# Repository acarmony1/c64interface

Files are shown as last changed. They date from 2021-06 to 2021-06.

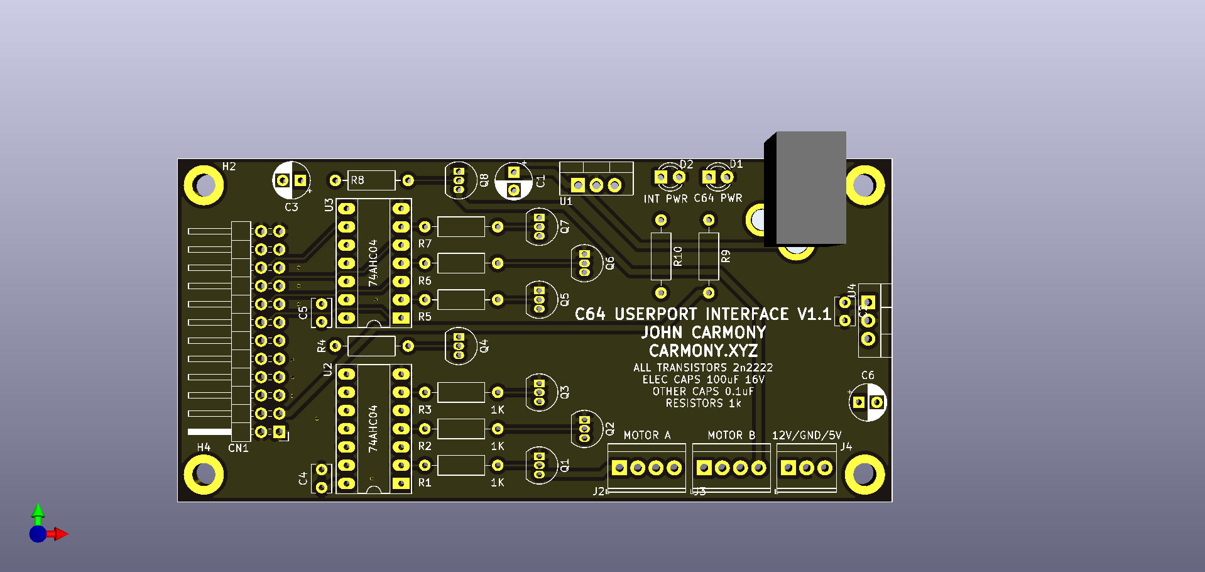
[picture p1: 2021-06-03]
kicad/c64interface.png

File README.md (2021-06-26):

# c64interface
 Commdore 64 Userport Interface
 
 I have been working on interface for the Commodore 64's userport. This interface allows user to use the C64 like you would any microcontroller. At this time it only turns on and off 8 pins, pins PB0-7.

There are many things that can be done with the C64's userport, which I will be looking into adding in the future. For now take a look at acarmony1/c64interface: Commodore 64 Userport Interface (github.com) for more information, schematics, and a demo program.

https://carmony.xyz/10-commodore/commodore-64-projects/9-c64-userport-interface.html

https://carmony.xyz/

Use the interface.prg as a demo to use this interface. Take note if the interface is powered up, and the C64 is off all ports are turned ON. This was the design I used from the Projects for the C64 book. In future versions, I may impletment a 'fail safe', where if no power from the C64 the unit shuts down.

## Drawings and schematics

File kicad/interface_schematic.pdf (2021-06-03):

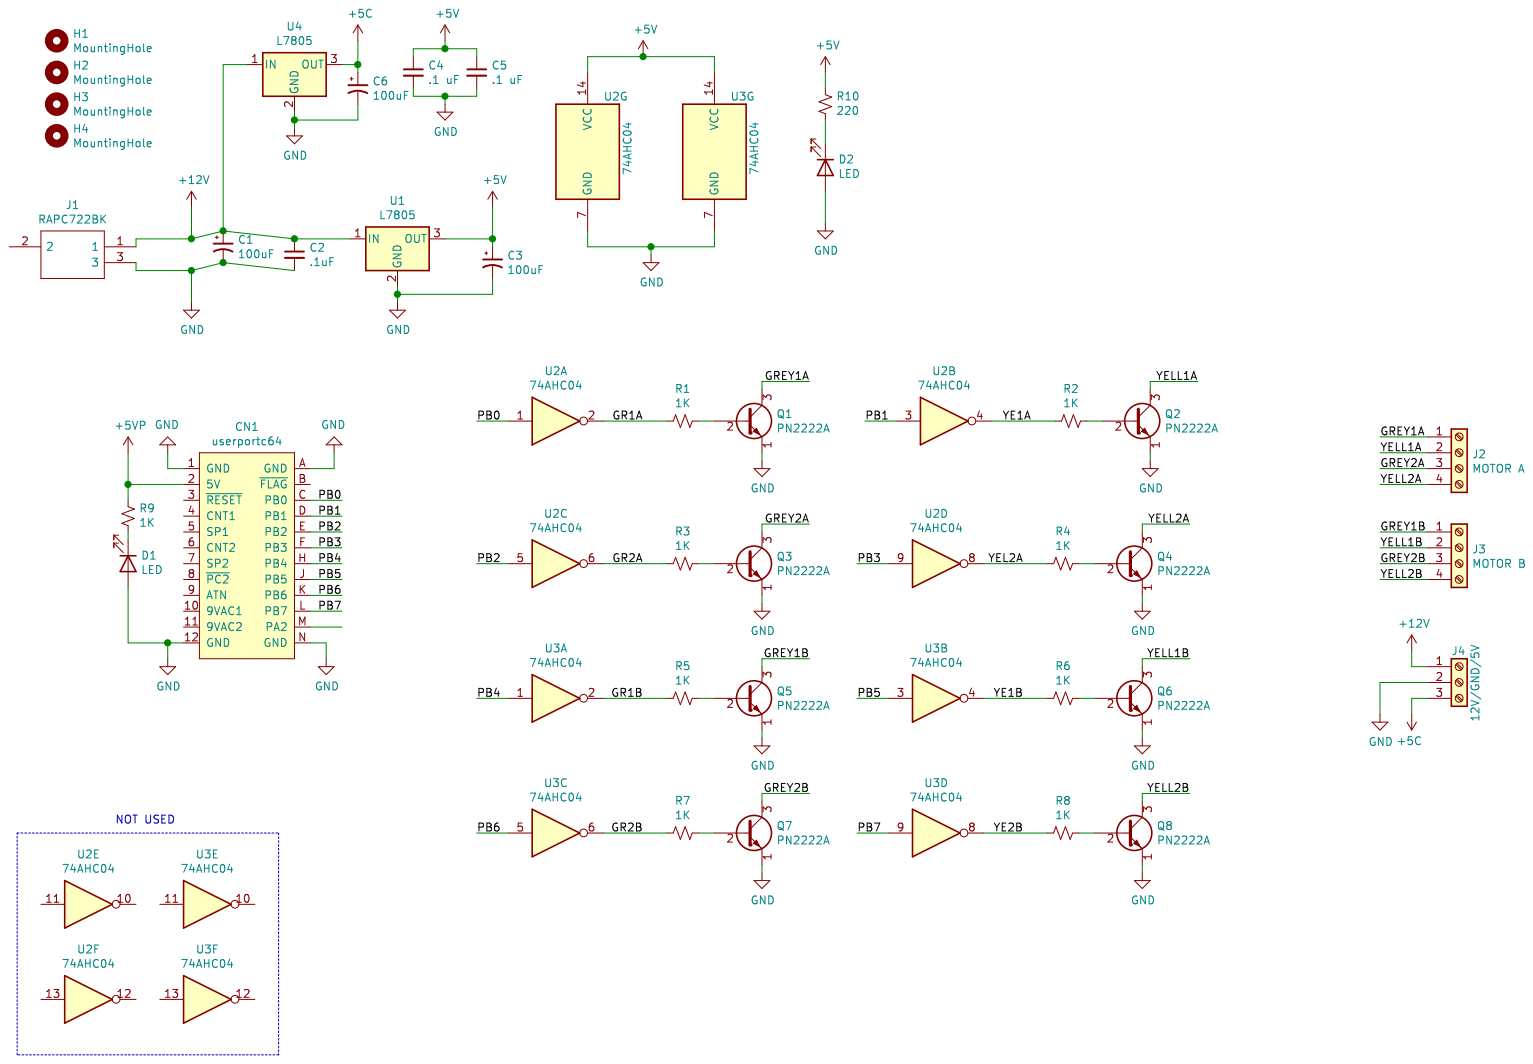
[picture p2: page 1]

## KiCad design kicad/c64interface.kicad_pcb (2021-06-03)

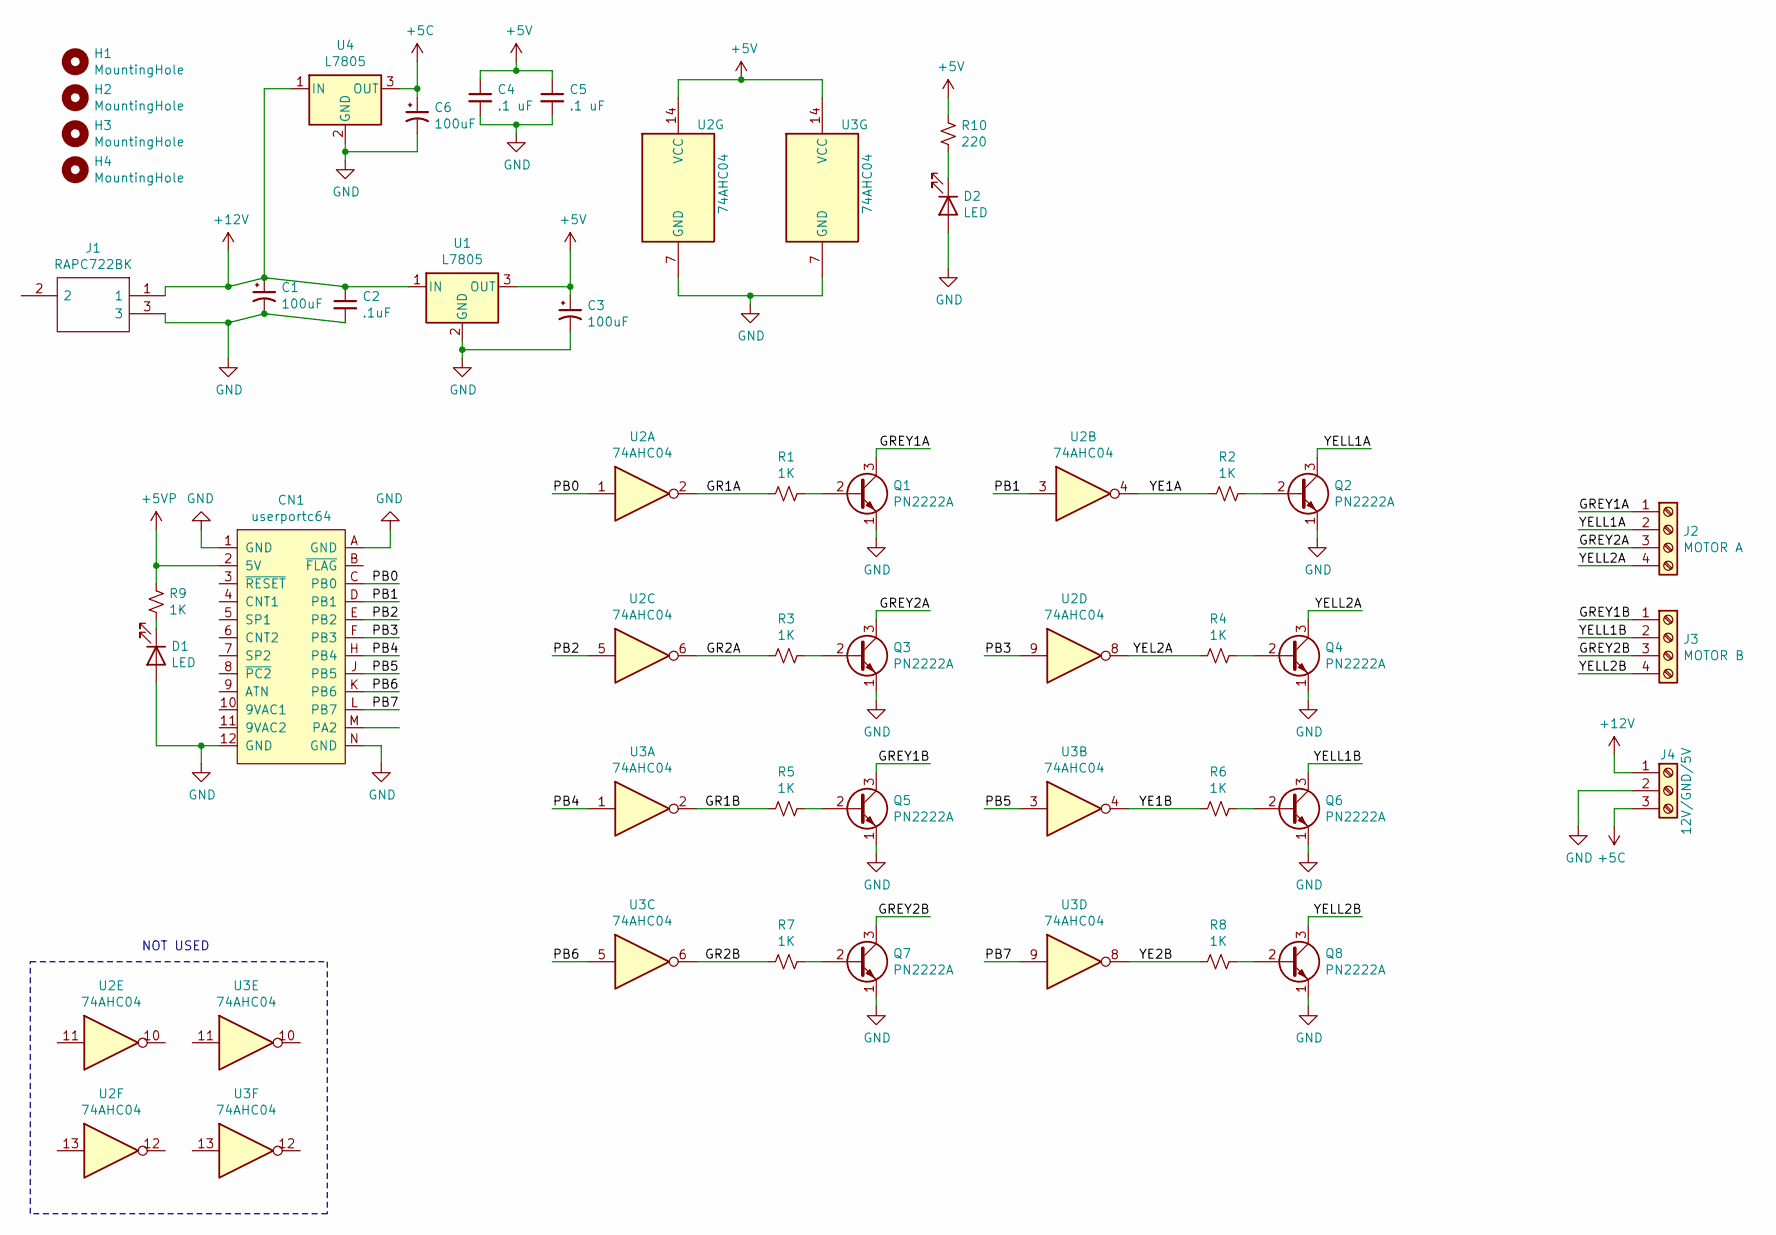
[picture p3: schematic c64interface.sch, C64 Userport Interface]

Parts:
C1, C3, C6: 100uF; CP_Radial_D5.0mm_P2.50mm
C2: .1uF; C_Disc_D3.8mm_W2.6mm_P2.50mm
C4, C5: .1 uF; C_Disc_D3.8mm_W2.6mm_P2.50mm
CN1: userportc64; PinHeader_2x12_P2.54mm_Horizontal
D1, D2: LED; LED_D3.0mm
H1, H2, H3, H4: MountingHole; MountingHole_3.2mm_M3_DIN965_Pad
J1: RAPC722BK; Mouser Part Number 502-RAPC722BK
J2: MOTOR A; TerminalBlock_TE_282834-4_1x04_P2.54mm_Horizontal
J3: MOTOR B; TerminalBlock_TE_282834-4_1x04_P2.54mm_Horizontal
J4: 12V/GND/5V; TerminalBlock_TE_282834-3_1x03_P2.54mm_Horizontal
Q1, Q2, Q3, Q4, Q5, Q6, Q7, Q8: PN2222A; TO-92_Inline
R1, R2, R3, R4, R5, R6, R7, R8, R9: 1K; R_Axial_DIN0207_L6.3mm_D2.5mm_P10.16mm_Horizontal
R10: 220; R_Axial_DIN0207_L6.3mm_D2.5mm_P10.16mm_Horizontal
U1, U4: L7805; TO-220-3_Vertical
U2, U3: 74AHC04; DIP-14_W7.62mm_Socket_LongPads

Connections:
+5C: C6.1, J4.3, U4.3 (OUT)
+5V: C3.1, C4.1, C5.1, R10.2, U1.3 (OUT), U2.14 (VCC), U3.14 (VCC)
+5VP: CN1.2 (5V), R9.2
+12V: C1.1, C2.1, J1.1, J4.1, U1.1 (IN), U4.1 (IN)
/GR1A: R1.2, U2.2
/GR1B: R5.2, U3.2
/GR2A: R3.2, U2.6
/GR2B: R7.2, U3.6
/GREY1A: J2.1, Q1.3 (C)
/GREY1B: J3.1, Q5.3 (C)
/GREY2A: J2.3, Q3.3 (C)
/GREY2B: J3.3, Q7.3 (C)
/PB0: CN1.C (PB0), U2.1
/PB1: CN1.D (PB1), U2.3
/PB2: CN1.E (PB2), U2.5
/PB3: CN1.F (PB3), U2.9
/PB4: CN1.H (PB4), U3.1
/PB5: CN1.J (PB5), U3.3
/PB6: CN1.K (PB6), U3.5
/PB7: CN1.L (PB7), U3.9
/YE1A: R2.2, U2.4
/YE1B: R6.2, U3.4
/YE2B: R8.2, U3.8
/YEL2A: R4.2, U2.8
/YELL1A: J2.2, Q2.3 (C)
/YELL1B: J3.2, Q6.3 (C)
/YELL2A: J2.4, Q4.3 (C)
/YELL2B: J3.4, Q8.3 (C)
GND: C1.2, C2.2, C3.2, C4.2, C5.2, C6.2, CN1.1 (GND), CN1.12 (GND), CN1.A (GND), CN1.N (GND), D1.2 (A), D2.2 (A), J1.3, J4.2, Q1.1 (E), Q2.1 (E), Q3.1 (E), Q4.1 (E), Q5.1 (E), Q6.1 (E), Q7.1 (E), Q8.1 (E), U1.2 (GND), U2.7 (GND), U3.7 (GND), U4.2 (GND)
unnamed: D1.1 (K), R9.1
unnamed: D2.1 (K), R10.1
unnamed: Q1.2 (B), R1.1
unnamed: Q2.2 (B), R2.1
unnamed: Q3.2 (B), R3.1
unnamed: Q4.2 (B), R4.1
unnamed: Q5.2 (B), R5.1
unnamed: Q6.2 (B), R6.1
unnamed: Q7.2 (B), R7.1
unnamed: Q8.2 (B), R8.1

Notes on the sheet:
NOT USED

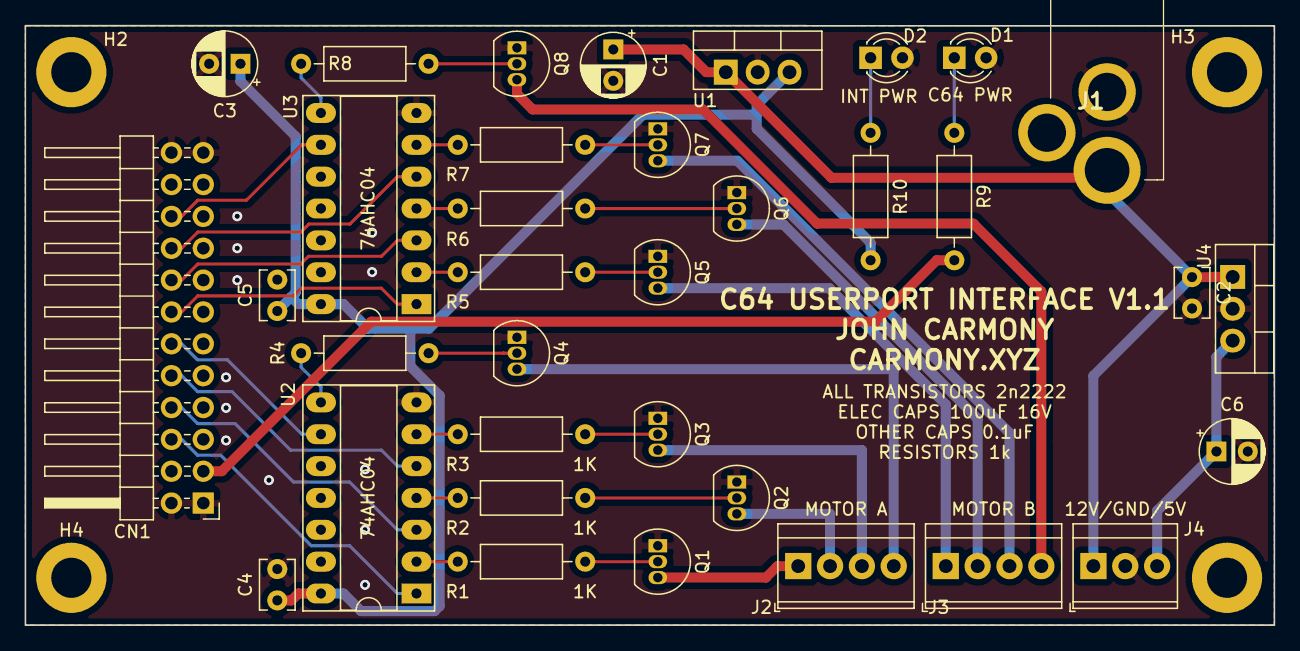
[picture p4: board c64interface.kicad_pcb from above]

Board: 2 copper layers, 99.6 x 47.8 mm, 39 parts (0 on the bottom side), 39 nets.

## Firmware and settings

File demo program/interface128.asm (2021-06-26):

;version 1.2 	5-25-2021
;version 1.3	6-26-2021		; cosmetic changes, isr handling optimize, changed to tass assembler, added 128 version;64tass.exe ./interface/interface128.asm -o ./interface/interface128.prg
;acme --cpu 6510 -f cbm -o ./interface/interface128.prg interface/interface128.asm
;exomizer sfx $1c10 -t128 ./interface/interface128.prg -o ./interface/interface128c.prg -Di_effect=2 -x "inc $d020"
;exomizer sfx $1c10 -t128 ./interface/interface128.prg -o ./interface/interface128c.prg -Di_effect=2 -x "inc $fb lda $fb sta $d020 lda #0 sta $d020"
;exomizer sfx $1c10 -t128 ./interface/interface128.prg -o ./interface/interface128c.prg -Di_effect=2 -x "inc $d020 inc $d021 lda #0 sta $d020 sta $d021"



clrscreen	= $e544
portout		= $dd03				; set ports to 255 (output) (#56579)
portloc		= $dd01				; 8-bit controller (0-7)	(#56577)
screenloc	= $0400				; beginning of screen location
borderloc	= $d020				; boreder color location
backgrloc	= $d021				; background color location
setchar		= $0a2c				; 128		;$d018				; charater location
isr			= $0314				; interupt location
returnint	= $ea31				; rti
char		= $3000				; custom char loc
charoff		= $18
ssizel		= $00				; size of screen in LO/HI
ssizeh		= $04
csizel		= $c0				; size of char set LO/HI
csizeh		= $0f
textcolor	= $05				; text color ($05 = white)
bordbackcol	= $00				; background and border color ($00 = black)
on			= $01				; on bit
off			= $00				; off bit


	;
	;	KERNAL FUNCTIONS
	;
	

chrout 		= $ffd2				;write byte to default output. (if not screen, must call open and chkout beforehands.)
								;input: a = byte to write.
								;output: –
								;used registers: –
								;real address: ($0326), $f1ca.
								
plot 		= $cc6a				;128	;$fff0				;save or restore cursor position.
								;input: carry: 0 = restore from input, 1 = save to output; x = cursor column (if carry = 0); y = cursor row (if carry = 0).
								;output: x = cursor column (if carry = 1); y = cursor row (if carry = 1).
								;used registers: x, y.
								;real address: $e50a.
								
getin 		= $eeeb				;128	;$ffe4				;read byte from default input. (if not keyboard, must call open and chkin beforehands.)
								;input: –
								;output: a = byte read.
								;used registers: a, x, y.
								;real address: ($032a), $f13e.

	;	
	;	screen loctions
	;

pbloc		= $04a9				; screen locations (add 3 for each port) 04d1


	;
	;	PORTS
	;
	
pboutput	= %11111111			; 255	(userport output)	
pboff		= %00000000			; 0 	(all off)	
pb0			= %00000001			; 1		(port0)
pb1			= %00000010			; 2 	(port1)
pb2			= %00000100			; 4		(port2)
pb3			= %00001000			; 8		(port3)
pb4			= %00010000			; 16	(port4)
pb5			= %00100000			; 32	(port5)
pb6			= %01000000			; 64	(port6)
pb7			= %10000000			; 128	(port7)
pball		= %11111111			; 255 	(all on)

zp1			= $fb				; zero page 1 location
zp2			= $fd				; zero page 2 location
zp3			= $fe				; zero page 3 location


rvson		= $80				; scrren code to turn ON reverse character
rvsoff		= $7f				; screen code to turn OFF reverse character


	;
	; BASIC STUB
	; 10 SYS (2064)
	; uncomment the following line to start as basic program

;	basic start
;
;*			= $1c01
;bstart		.byte $0d, $08, $0a, $00, $9e
;btext		.text "7184"			; Start address! Be *very* careful!
;			
;	basic stop

*			= $1c10				; SYS7184


codeentry	jsr init			; setup and initialize
						
			jmp loop			; jump to loop
			

init		sei					; stop interupt operation (needed to setup new ISR)
			
			lda #textcolor		; set char color
			jsr clearscreen		; clear the screen
			
			
			;jsr chrout
						
			lda setchar			; get current char info
			sta charbackup		; store it to recover later
			
			; start custom charset code , it is not needed for functionality
			
			lda #<charset		; load custom char set (LO byte)
			ldy #>charset		; (HI byte)
			sta zp1				; set zero page 1
			sty zp1+1
			
			lda #<char			; load to this location (LO byte)
			ldy #>char			; (HI byte)
			sta zp2				; set zero page 2
			sty zp2+1
			
			lda #csizel			; char set size to move (LO byte)
			ldy #csizeh			; (HI byte)
			sta sizel			; store it (LO byte)
			sty sizeh			; (HI byte)
			
			jsr movedown		; move the memory
			
			lda setchar			;#$18			; set to current char location
			and #240
			ora #12
			sta setchar
			
			; end of custom character code			
			

			
			lda #bordbackcol	; set border/background
			sta backgrloc
			sta borderloc
			
			sec
			jsr plot			; set plot points for screen
			stx xstore
			sty ystore		
			
			lda #<screentxt		; setup screen 				(LO byte)
			ldy #>screentxt		; 							(HI byte)	
			sta zp1				; set up zeropage 1 with screen text location (LO byte)
			sty zp1+1			;							(HI byte)
			
			lda #<screenloc		; setup scrren location		(LO byte)
			ldy #>screenloc		; 							(HI byte)
			sta zp2				; set up zeropage 2 with screen location ($0400) to move to (LO byte)
			sty zp2+1			; 							(HI byte)
			
			lda #ssizel			; set size of block to move	(LO byte) 
			ldy #ssizeh			; 							(HI byte)
			sta sizel			; store it 					(LO byte)
			sty sizeh			;							(HI byte)
			
			jsr movedown		; print screen (copy from location to location)
			
			lda #<portloc		; set portloc to zp3		(LO byte)
			ldy #>portloc		; 							(HI byte)
			sta zp3				; store it					(LO byte)
			sty zp3+1			; 							(HI byte)
			
			lda isr				; set up interupt backup	(LO byte)
			ldy isr+1			; to recover on exit		(HI byte)
			sta isrbackup		; store it					(LO byte)
			sty isrbackup+1		; 							(HI byte)
			
			lda #<startscan		; ISR is at this location	(LO byte)
			ldy #>startscan		; 							(Hi byte)
			sta isr				; store it					(LO byte)
			sty isr+1			;							(HI byte)
			
			lda #pboutput		; set ports to output
			sta portout			
			
			lda #pboff			; turn all ports off
			sta portloc
			
			lda #<pbloc			; port locations on screen	(LO byte)
			ldy #>pbloc			; add "3" for each port		(HI byte)			
			sta zp1
			sty zp1+1
			
			cli					; restore interupt operation
			
			rts
	
	
	;
	;	MOVE BLOCK MEMORY
	;


movedown	ldy #0
			ldx sizeh
			beq md2
md1  		lda (zp1),y 		; move a page at a time
			sta (zp2),y
			iny
			
			bne md1
			inc zp1+1			; 255 byte reached, increment hi byte
			inc zp2+1
			dex
			bne md1				; not finished
md2      	ldx sizel
			beq md4
md3      	lda (zp1),y			; move the remaining bytes
			sta (zp2),y
			iny
			dex
			bne md3
md4      	rts
			

exit		lda #pboff			; load all ports off (0)
			sta portloc			; store it in port	; update port status
			
			ldx xstore			; restore x
			ldy ystore			; restore y
			clc					
			jsr plot			; cursor position
			
			lda #textcolor
			jsr clearscreen		; clear the screen before exit
			
			sei					; stop interupt operations
			
			lda isrbackup		; load back previous	(LO byte)
			ldy isrbackup+1		; ISR location			(HI byte)
			sta isr
			sty isr+1
			
			lda charbackup		; restore char set to previous
			sta setchar	
			
			cli					; start interupt operations

			rts

		;	
		;	MAIN LOOP (ISR takes care of most functions)
		;
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
